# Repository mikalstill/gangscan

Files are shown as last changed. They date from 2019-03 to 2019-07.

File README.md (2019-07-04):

Introduction
============

Gang Scan is a simple attendance tracking system built for Scouts ACT's
Canberra Gang Show. It uses custom RFID badge reader devices based on
Raspberry Pis to track badge read events, which are streamed to a server.
Each badge reader is configured to either be an "in" or and "out" reader, and
therefore attendance can be calculated. The badge readers will queue scan
events and stream them to the server later if connectivity is intermittent.

Structure
=========

The structure of this repository is:

* deploy: deployment scripts.
* eagle: PCB layouts for the gang scan hardware.
* gangscan: the software stack for the badge readers.
* gangserver: the server side of the application.
* idcards: is a simple ID card art generation script with sample data. See the README in that directory for more detail.
* vendor: git sub-modules for dependancies.

Installation: Common Steps
==========================

First off, flash the latest raspberry pi debian to an SD card. You can find
it at https://www.raspberrypi.org/downloads/raspbian/ . I have been using the
Debian Stretch Lite image for development. I use Balena Etcher to flash the
SD cards, and this process is well documented elsewhere.

Insert this SD card into your raspberry pi and boot it. You'll need to have
the raspberry pi plugged into a HDMI monitor and USB keyboard and mouse for
the next steps.

* Log in: username is "pi" and password is "raspberry".
* Change the password: "passwd".
* Configure the pi:
  * `sudo raspi-config`
  * Join wifi (network options)
  * Enable ssh (interfacing options)
  * Expand filesystem (advanced options)
  * Reboot
* Update the operating system:
  * `sudo apt-get update`
  * `sudo apt-get dist-upgrade`
* Install ansible:
  * `sudo apt-get install python3-pip`
  * `sudo pip3 install ansible`
* Install git and vim, then clone gangscan:
  * `sudo apt-get install git vim`
  * `git clone https://github.com/mikalstill/gangscan`
  * `cd gangscan`
  * `git submodule update --init --recursive`

Installation: Gang Server
=========================

The gangserver advertises itself using a homegrown UDP protocol. It is assumed that
the server will be running on raspberry pi running debian (called raspbian).
This can be one of the gangscan devices if that is desirable for your
deployment. First follow the common installation steps above, once those
steps are done we have enough of a system to be able to do the rest of the
install via ansible plays.

Run ansible to install gangserver:

~~~~
$ /usr/local/bin/ansible-playbook -i hosts deploy/gangserver.yml
~~~~

This should install all the required software for the gangserver, and start
it on port 80. The server advertises itself on the network using avahi /
zeroconf networking, so you don't need to have the server running on a
machine with a known IP. However, knowing the IP of the server is very
useful for viewing reports, so perhaps put it on a static IP anyway.

Installation: Gang Scan
=======================

The RFID reader hardware runs a program called gangscan. To install it,
follow the common installation steps above, and then install gangscan with
ansible:

~~~~
$ /usr/local/bin/ansible-playbook -i hosts deploy/gangscan.yml
~~~~

Because the ansible changes the boot configuration of the raspberry pi (it
turns on SPI and PWN audio), you need to reboot before the scanner will work
correctly:

~~~~
$ sudo reboot
~~~~

Checking the status of Gang Scan
================================

Because Gang Scan uses systemd, you can check the status of the various
components using systemd commands. To see the general status of the server,
do this:

~~~~
$ sudo systemctl status gangserver
~~~~

To see recent log messages from the server, do this:

~~~~
$ sudo journalctl -u gangserver
~~~~

Hardware helpers
================

Gang Scan devices use an identity EEPROM to make sure the software is talking
to the right version of the hardware. To program EEPROMs, install the
developer software with Ansible like this:

~~~~
$ /usr/local/bin/ansible-playbook -i hosts deploy/eeprom_writer.yml
~~~~

Now we can program some EEPROMs. You'll need to build a little programming
circuit (see the notes below), and then run this tool:

~~~~
$ cd /home/pi/hats/eepromutils
$ sudo sh eepflash.sh -w -f=/home/pi/gangscan/eeprom/eeprom_settings.eep \
  -t=24c256 -d=1
~~~~

For more details about Raspberry Pi HAT EEPROMs, see my notes at
https://www.madebymikal.com/raspberry-pi-hat-identity-eeproms-a-simple-guide/

Credits
=======

Various parts of Gang Scan draw on previous Open Source or Creative Commons
artifacts:

* Material Design Icons are from https://cdn.materialdesignicons.com/3.5.95/.
** This includes the TTF Font, as well as account.png
* BebaseNeue is licensed under the creative commons and is from https://fontlibrary.org/en/font/bebas
* blip.wav is "Robot Blip" by Marianne Gagnon from http://soundbible.com/1682-Robot-Blip.html which is released under a CC Attribution 3.0 license.

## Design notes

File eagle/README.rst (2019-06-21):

Board notes:

* v0.1: the first board to be fabbed. Has LCD and RFID on different SPI buses.
* ... (incremental tweaking including better track sizing, and nicer labels)
* v0.6: the second board to be fabbed. Has LCD and RFID on different SPI buses, and prototype
  audio support. Unfortunately, SPI1 conflicts with the audio hardware and the RFID reader
  needs to be moved onto SPI0 for this to work correctly.
* v0.7: tweaked footprint labels to be more accurate. Moved RFID reader onto SPIO bus to free
  up pins for audio. Corrected MKT capacitor pitch to 5mm.
* v0.8: correct resistor pitch (RCL_0207/7); connect RFID IRQ line to Raspberry Pi for
  later use (reduce CPU load for RFID reads by avoiding polling); moved LiPo socket down a
  little so the JST connector fits more naturally into a case; added an i2c EEPROM to
  comply with the HAT specification.

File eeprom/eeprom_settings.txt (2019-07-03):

########################################################################
# EEPROM settings text file
#
# Edit this file for your particular board and run through eepmake tool,
# then use eepflash tool to write to attached HAT ID EEPROM 
#
# Tools available:
#  eepmake   Parses EEPROM text file and creates binary .eep file
#  eepdump   Dumps a binary .eep file as human readable text (for debug)
#  eepflash  Write or read .eep binary image to/from HAT EEPROM
#
########################################################################

########################################################################
# Vendor info

# 128 bit UUID. If left at zero eepmake tool will auto-generate
# RFC 4122 compliant UUID
product_uuid 00000000-0000-0000-0000-000000000000

# 16 bit product id
product_id 0x0001

# 16 bit product version
product_ver 0x0008

# ASCII vendor string  (max 255 characters)
vendor "madebymikal.com"

# ASCII product string (max 255 characters)
product "GangScan"

########################################################################
# GPIO bank settings, set to nonzero to change from the default.
# NOTE these setting can only be set per BANK, uncommenting any of
# these will force the bank to use the custom setting.

# drive strength, 0=default, 1-8=2,4,6,8,10,12,14,16mA, 9-15=reserved
gpio_drive 0

# 0=default, 1=slew rate limiting, 2=no slew limiting, 3=reserved
gpio_slew 0

# 0=default, 1=hysteresis disabled, 2=hysteresis enabled, 3=reserved
gpio_hysteresis 0

# If board back-powers Pi via 5V GPIO header pins:
# 0 = board does not back-power
# 1 = board back-powers and can supply the Pi with a minimum of 1.3A
# 2 = board back-powers and can supply the Pi with a minimum of 2A
# 3 = reserved
# If back_power=2 then USB high current mode will be automatically 
# enabled on the Pi
back_power 0

########################################################################
# GPIO pins, uncomment for GPIOs used on board
# Options for FUNCTION: INPUT, OUTPUT, ALT0-ALT5
# Options for PULL: DEFAULT, UP, DOWN, NONE
# NB GPIO0 and GPIO1 are reserved for ID EEPROM so cannot be set

#         GPIO  FUNCTION  PULL
#         ----  --------  ----
#setgpio  2     INPUT     DEFAULT
#setgpio  3     INPUT     DEFAULT
#setgpio  4     INPUT     DEFAULT
#setgpio  5     INPUT     DEFAULT
#setgpio  6     INPUT     DEFAULT
#setgpio  7     INPUT     DEFAULT
#setgpio  8     INPUT     DEFAULT
#setgpio  9     INPUT     DEFAULT
#setgpio  10    INPUT     DEFAULT
#setgpio  11    INPUT     DEFAULT
#setgpio  12    INPUT     DEFAULT
#setgpio  13    INPUT     DEFAULT
#setgpio  14    INPUT     DEFAULT
#setgpio  15    INPUT     DEFAULT
#setgpio  16    INPUT     DEFAULT
#setgpio  17    INPUT     DEFAULT
#setgpio  18    INPUT     DEFAULT
#setgpio  19    INPUT     DEFAULT
#setgpio  20    INPUT     DEFAULT
#setgpio  21    INPUT     DEFAULT
#setgpio  22    INPUT     DEFAULT
#setgpio  23    INPUT     DEFAULT
#setgpio  24    INPUT     DEFAULT
#setgpio  25    INPUT     DEFAULT
#setgpio  26    INPUT     DEFAULT
#setgpio  27    INPUT     DEFAULT

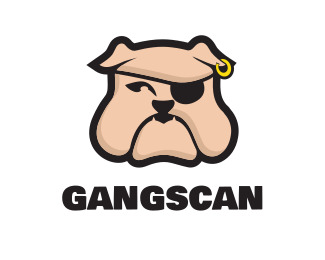
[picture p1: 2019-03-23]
idcards/logo.jpg

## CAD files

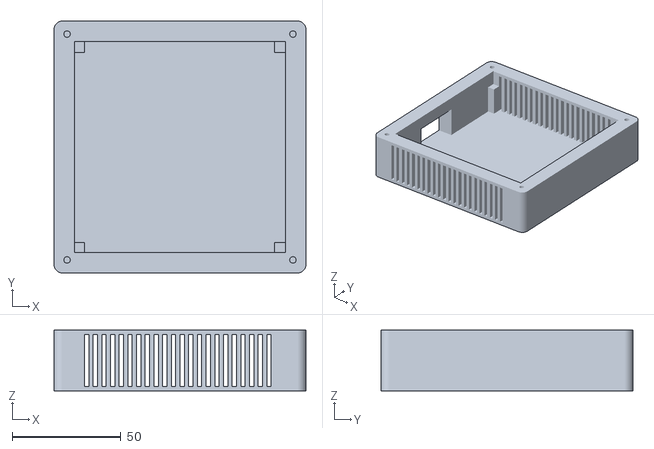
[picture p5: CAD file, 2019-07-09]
cases/gangscan_case.stl
116.0 x 116.0 x 28.0

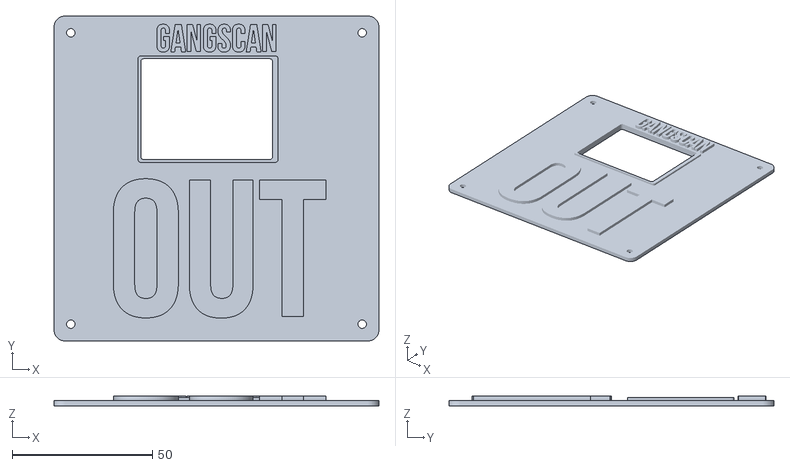
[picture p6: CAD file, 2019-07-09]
cases/gangscan_out.stl
116.0 x 116.0 x 3.50

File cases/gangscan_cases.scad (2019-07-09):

// Gangscan case
// This is a case built for the gangscan project
// https://github.com/mikalstill/gangscan
// the BebasNeue.ttf font from the gangscan directory needs to be installed to render correctly

// The dimensions of the board are added here as debug objects
// gangscan board
%cube([96,96,1.7]);
// screen board
%translate([8.25,53.75,3.1]) cube([68,40,1.5]);
// screen hole
%translate([21,54.75,4.6]) cube([48,36,5.5]); // 4mm extra to see where the hole goes. Needs to be smaller than the screen bracket
// rfid reader
%translate([8.25,8,3.7]) cube([60,40,1.5]);
// Raspberry Pi Zero W
%translate([8.25,21,-18]) cube([30,65,18]);


module PowerSymbol (thickness) {
    // we need a power symbol on the side
    linear_extrude (height = thickness, center = true, convexity = 1, twist = 0, slices = 10, scale = 1.0, $fn = 100) {
        union() {
            difference () {
                circle (10, $fn=100);
                circle (8, $fn=100);
                translate ([-3,0,0]) square ([6,10]);
            }
            translate ([-1,2,0]) square ([2,10]);
        } 
    }
}// power symbol

module USBSymbol (thickness) {
    // we don't really need a usb symbol
    // but it's a good learning exercise to have done this by hand
    linear_extrude (height = thickness, center = true, convexity = 1, twist = 0, slices = 10, scale = 1.0, $fn = 100) {
    // This array is the points to generate the USB trident without the circles    
        usbTrident=[[0,0],[0,0.5],[6,0.5],[10,5],[15,5], [15,4],[10,4],[7,0.5],[20,0.5],[20,2],[23,0],[20,-2],[20,-0.5],[10,-0.5],[13,-4],[16,-4],[16,-3],[19,-3],[19,-6],[16,-6],[16,-5],[13,-5],[9,-0.5]
    ,[0,-0.5]];
        union () {
            polygon(usbTrident);
            // add the circles to the shape
            circle (2, $fn=50); 
            translate ([15,4.5,0]) circle (1.5, $fn=50); 
        } // union
    } //linear_extrude
}// USBsymbol

module RoundBox (x, y, z, r) {
  $fn=50;
  translate ([r, r, 0]) minkowski()
  {
    cube([x-(2*r), y-(2*r), z]);
    cylinder(r=r, h=z);
  }
} // RoundBox



module Lid (direction) {
// Top Half with the out text
// uncomment the rotate/translate for export
//rotate([180,0,0]) translate ([0, -90, -10])
    difference() {
        union() {
            translate ([-10, -10, 8]) RoundBox(116, 116, 1, 4);  // box height is double the value set
            translate ([20, 53.75, 10]) RoundBox(50, 38, 0.5,1); // Add a border to the screen

            // gangscan text
            translate ([ 48,98, 10]) linear_extrude (height = 3, center = true, convexity = 1, twist = 0, slices = 10, scale = 1.0, $fn = 100) {
    text("GANGSCAN", halign="center", valign="center", font="Bebas Neue:style=Regular");
            }
            // direction text
            translate ([48, 22.5, 10]) linear_extrude (height = 3, center = true, convexity = 1, twist = 0, slices = 10, scale = 1.0, $fn = 100) {
    text(direction, halign="center", valign="center", font="Bebas Neue:style=Regular", size=50);
            }
        }
        // screen hole
        translate([21,54.75,0]) RoundBox(47, 36, 10.5,1);
        // Holes for the screws
        translate ([-4, -4, 3]) cylinder(8, d=3, $fn=50);
        translate ([-4, 100, 3]) cylinder(8, d=3, $fn=50);
        translate ([100, -4, 3]) cylinder(8, d=3, $fn=50);
        translate ([100, 100, 3]) cylinder(8, d=3, $fn=50);
    } // difference
} // lid ()




module Case() {
// Bottom Half
// uncomment the translate to export
    union() {
        difference() {
            translate ([-10, -10, -20]) RoundBox(116, 116, 14, 4);  // box height is double the value set
            // cut out the hole for the board
            translate([-0.5, -0.5, -18]) cube([97,97,28]);
            // and the holes for the screws
            translate ([-4, -4, -15]) cylinder(25, d=3, $fn=50);
            translate ([-4, 100, -15]) cylinder(25, d=3, $fn=50);
            translate ([100, -4, -15]) cylinder(25, d=3, $fn=50);
            translate ([100, 100, -15]) cylinder(25, d=3, $fn=50);
            // USB hole for the raspberry pi
            translate([-10, 25, -18]) cube([20,30,18]);
            // show which side is power
            translate([-10, 15, -10]) rotate ([90,0,-90]) scale ([0.5, 0.5, 1]) PowerSymbol (3);
            // and USB
            translate([-10, 65, -14]) rotate ([90,-90,-90]) scale ([0.5, 0.5, 1]) USBSymbol (3);
            // add some vents
            for (counter = [1:22]) {
                translate([0+(4 * counter), -10, -18]) cube([2,20,24]);
                translate([0+(4 * counter), 86, -18]) cube([2,20,24]);
            }
        } // difference
        // supports for the board
        translate ([-1, -1, -18]) cube([5,5,17]);
        translate ([-1, 91.5, -18]) cube([5,5,17]);
        translate ([91.5, -1, -18]) cube([5,5,17]);
        translate ([91.5, 91.5, -18]) cube([5,5,17]);
    } // union
} // case

// align them nicely
translate ([0, 0, -8]) Lid ("IN");
translate ([0, -120, -8]) Lid ("OUT");
translate ([0, 120, 20]) Case () ;

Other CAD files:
cases/gangscan_in.stl

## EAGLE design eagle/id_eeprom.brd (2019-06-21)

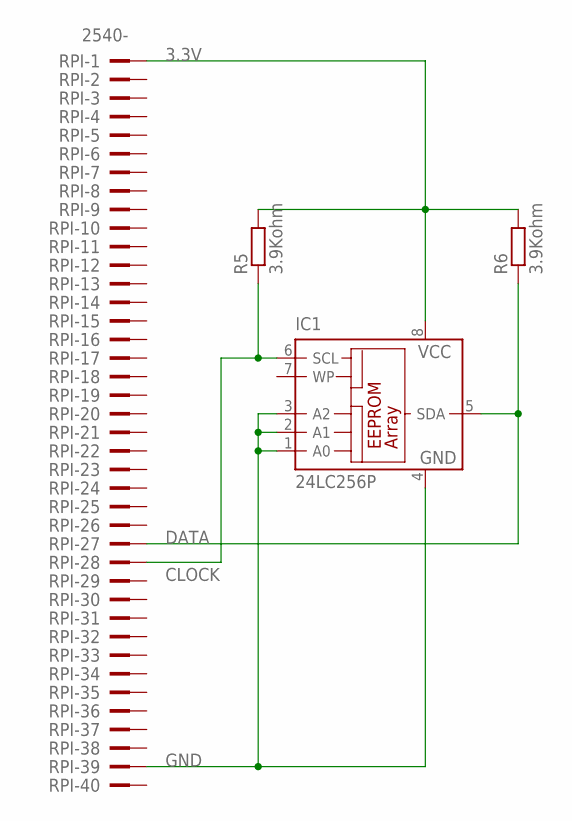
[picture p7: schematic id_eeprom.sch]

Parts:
IC1: 24LC256P; DIL8
R5, R6: 3.9Kohm; 0207/7
RPI: 2540-; PAK100/2500-40

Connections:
3.3V: IC1.8 (VCC), R5.2, R6.2, RPI.1
CLOCK: IC1.6 (SCL), R5.1, RPI.28
DATA: IC1.5 (SDA), R6.1, RPI.27
GND: IC1.1 (A0), IC1.2 (A1), IC1.3 (A2), IC1.4 (GND), RPI.39

Board: 2 copper layers, 4 parts (0 on the bottom side), 4 nets, no tracks yet.

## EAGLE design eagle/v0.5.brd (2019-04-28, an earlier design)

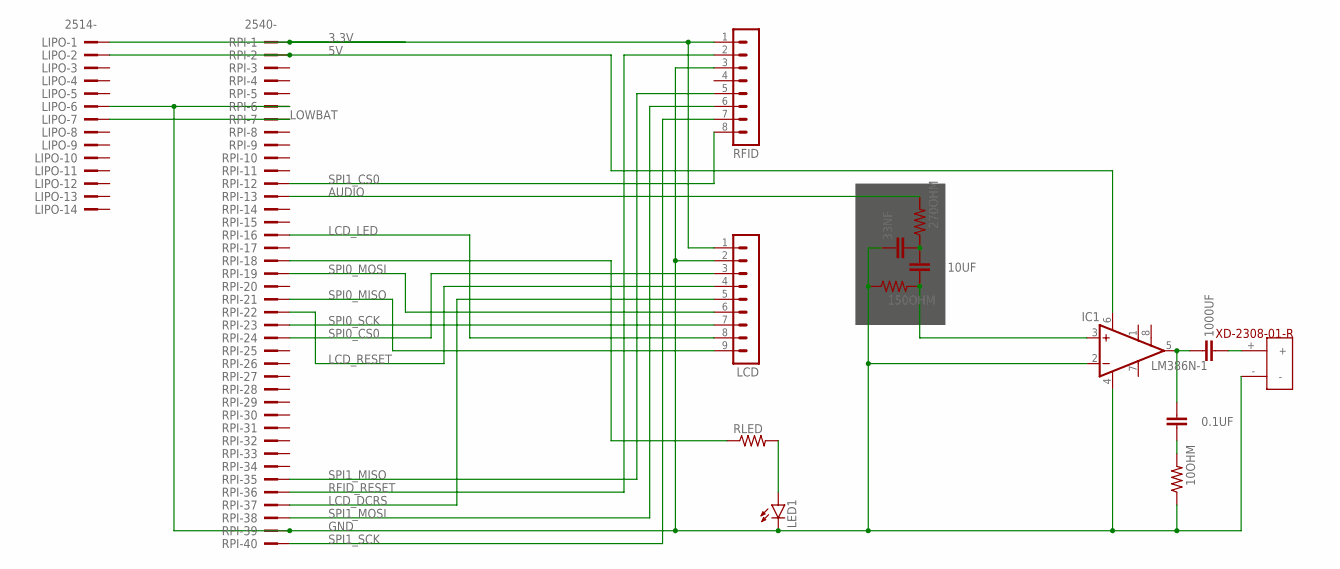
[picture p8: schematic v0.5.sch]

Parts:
0.1UF, 10UF, 33NF, 1000UF: C-EU025-025X050; C025-025X050
10OHM, 150OHM, 270OHM: R-US_0204/5; 0204/5
IC1: LM386N-1; DIL08
LCD: MA09-1
LED1: LED3MM
LIPO: 2514-; PAK100/2500-14
RFID: MA08-1
RLED: R-US_0204/5; 0204/5
RPI: 2540-; PAK100/2500-40
U$1: XD-2308-01-R

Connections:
3.3V: LCD.1, LIPO.1, RFID.1, RPI.1
5V: IC1.6 (VS), LIPO.2, RPI.2
AUDIO: 270OHM.2, RPI.13
GND: 10OHM.1, 33NF.1, 150OHM.1, IC1.2 (-IN), IC1.4 (GND), LCD.2, LED1.K (C), LIPO.6, RFID.3, RPI.6, RPI.39, U$1.-
LCD_DCRS: LCD.5, RPI.37
LCD_LED: LCD.8, RPI.16
LCD_RESET: LCD.4, RPI.22
LOWBAT: LIPO.7, RPI.7
unnamed: 10UF.2, 33NF.2, 270OHM.1
unnamed: 10UF.1, 150OHM.2, IC1.3 (+IN)
unnamed: RLED.1, RPI.18
unnamed: 0.1UF.2, 1000UF.2, IC1.5 (OUT)
unnamed: 1000UF.1, U$1.+
unnamed: 0.1UF.1, 10OHM.2
unnamed: LED1.A, RLED.2
RFID_RESET: RFID.2, RPI.36
SPI0_CS0: LCD.3, RPI.24
SPI0_MISO: LCD.9, RPI.21
SPI0_MOSI: LCD.6, RPI.19
SPI0_SCK: LCD.7, RPI.23
SPI1_CS0: RFID.8, RPI.12
SPI1_MISO: RFID.5, RPI.35
SPI1_MOSI: RFID.6, RPI.38
SPI1_SCK: RFID.7, RPI.40

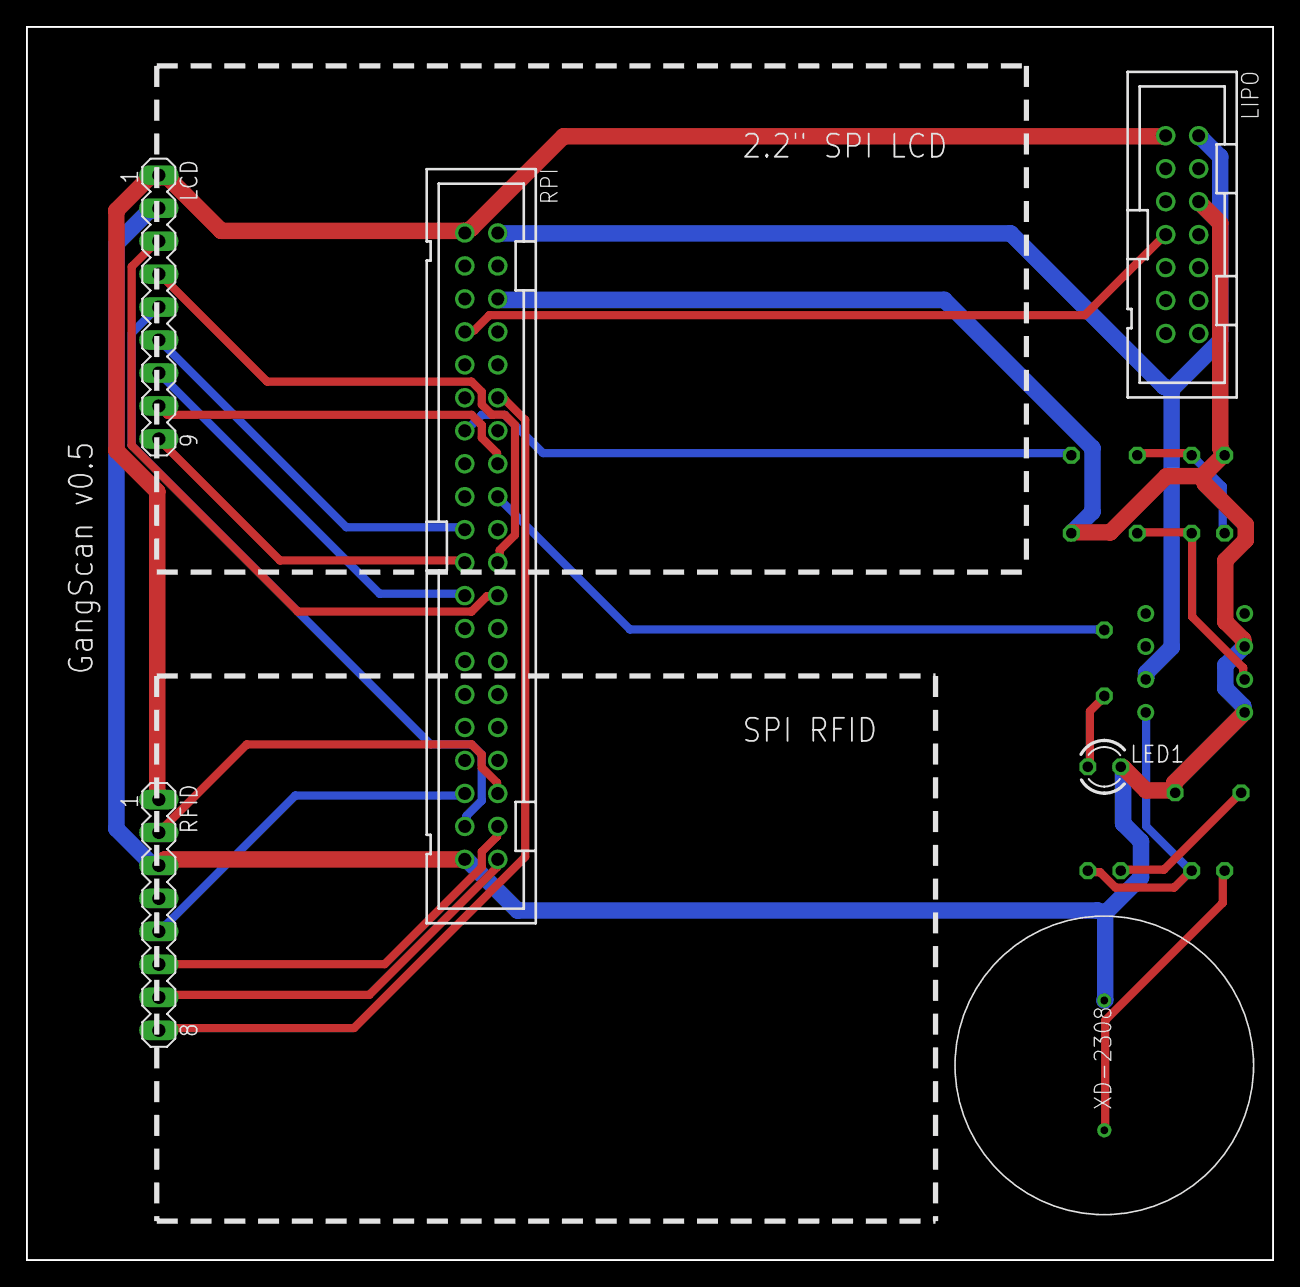
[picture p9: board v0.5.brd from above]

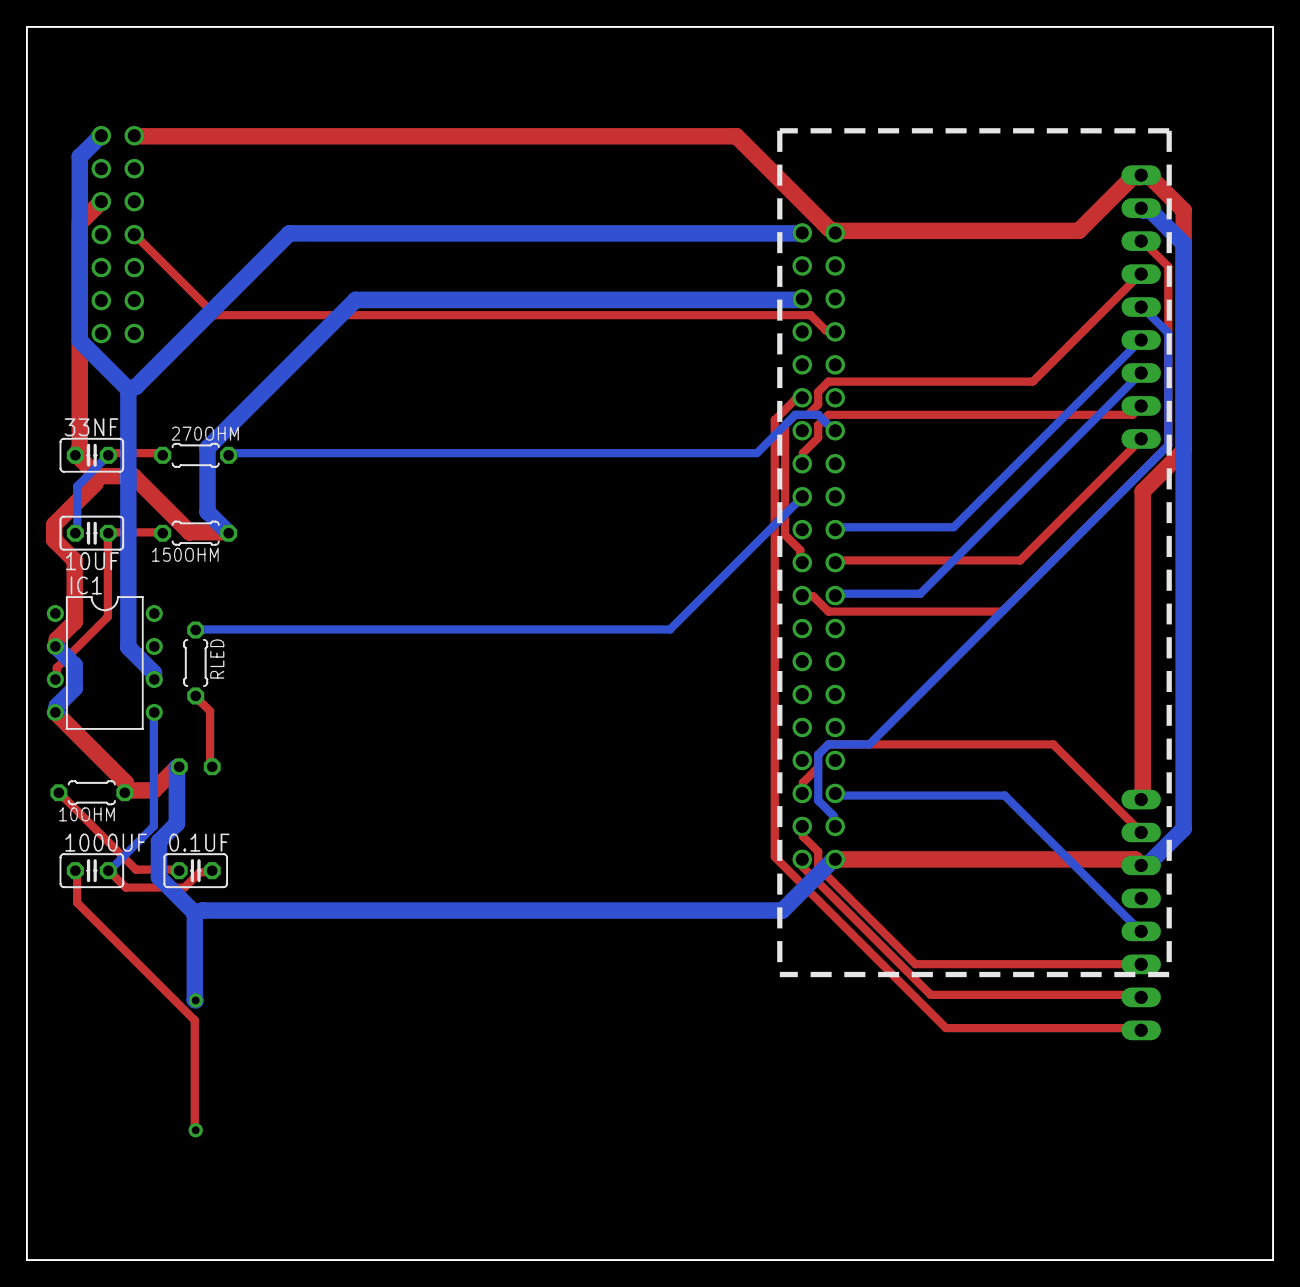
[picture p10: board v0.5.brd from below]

Board: 2 copper layers, 96.0 x 95.0 mm, 15 parts (9 on the bottom side), 24 nets.

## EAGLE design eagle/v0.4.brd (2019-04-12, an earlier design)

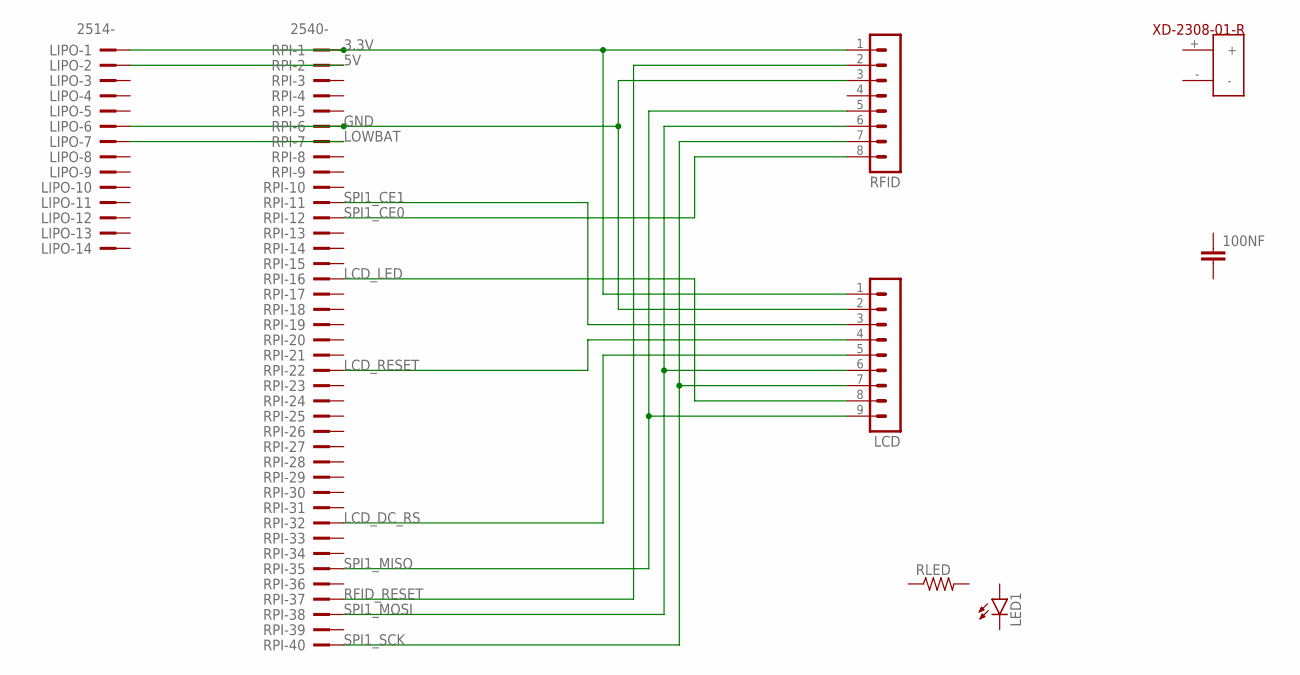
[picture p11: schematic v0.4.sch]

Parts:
100NF: C-EU025-025X050; C025-025X050
LCD: MA09-1
LED1: LED3MM
LIPO: 2514-; PAK100/2500-14
RFID: MA08-1
RLED: R-US_0204/5; 0204/5
RPI: 2540-; PAK100/2500-40
U$1: XD-2308-01-R

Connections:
3.3V: LCD.1, LIPO.1, RFID.1, RPI.1
5V: LIPO.2, RPI.2
GND: LCD.2, LIPO.6, RFID.3, RPI.6
LCD_DC_RS: LCD.5, RPI.32
LCD_LED: LCD.8, RPI.16
LCD_RESET: LCD.4, RPI.22
LOWBAT: LIPO.7, RPI.7
RFID_RESET: RFID.2, RPI.37
SPI1_CE0: RFID.8, RPI.12
SPI1_CE1: LCD.3, RPI.11
SPI1_MISO: LCD.9, RFID.5, RPI.35
SPI1_MOSI: LCD.6, RFID.6, RPI.38
SPI1_SCK: LCD.7, RFID.7, RPI.40

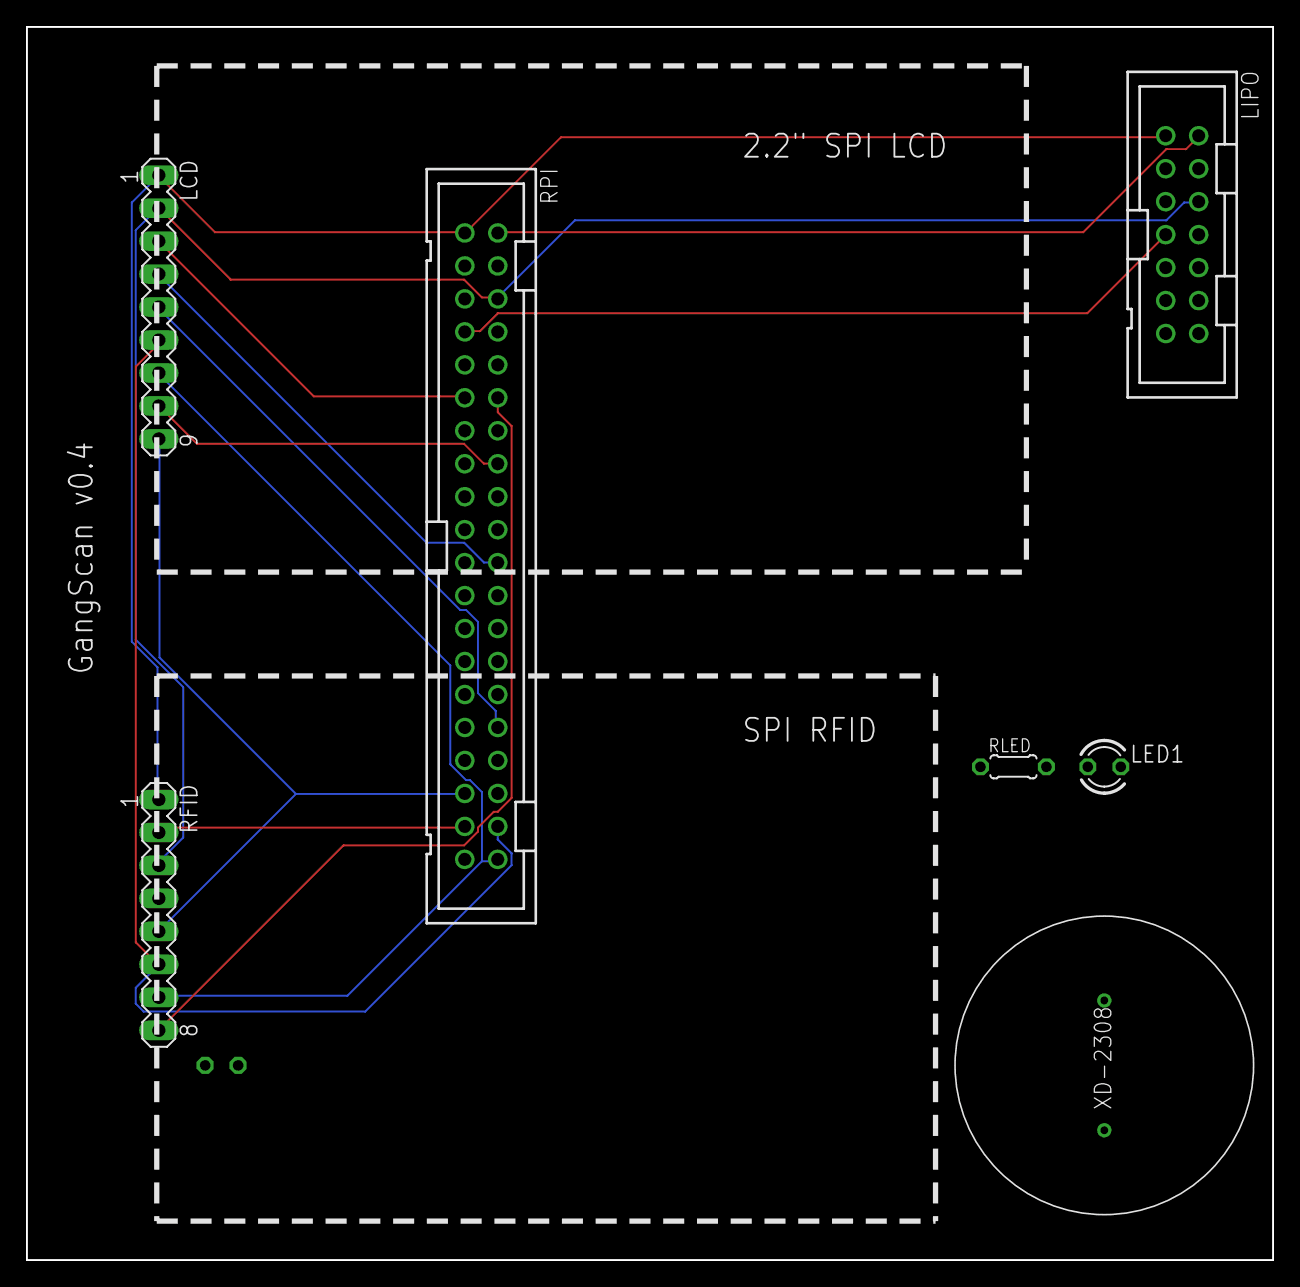
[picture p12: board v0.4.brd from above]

Board: 2 copper layers, 96.0 x 95.0 mm, 8 parts (1 on the bottom side), 13 nets.

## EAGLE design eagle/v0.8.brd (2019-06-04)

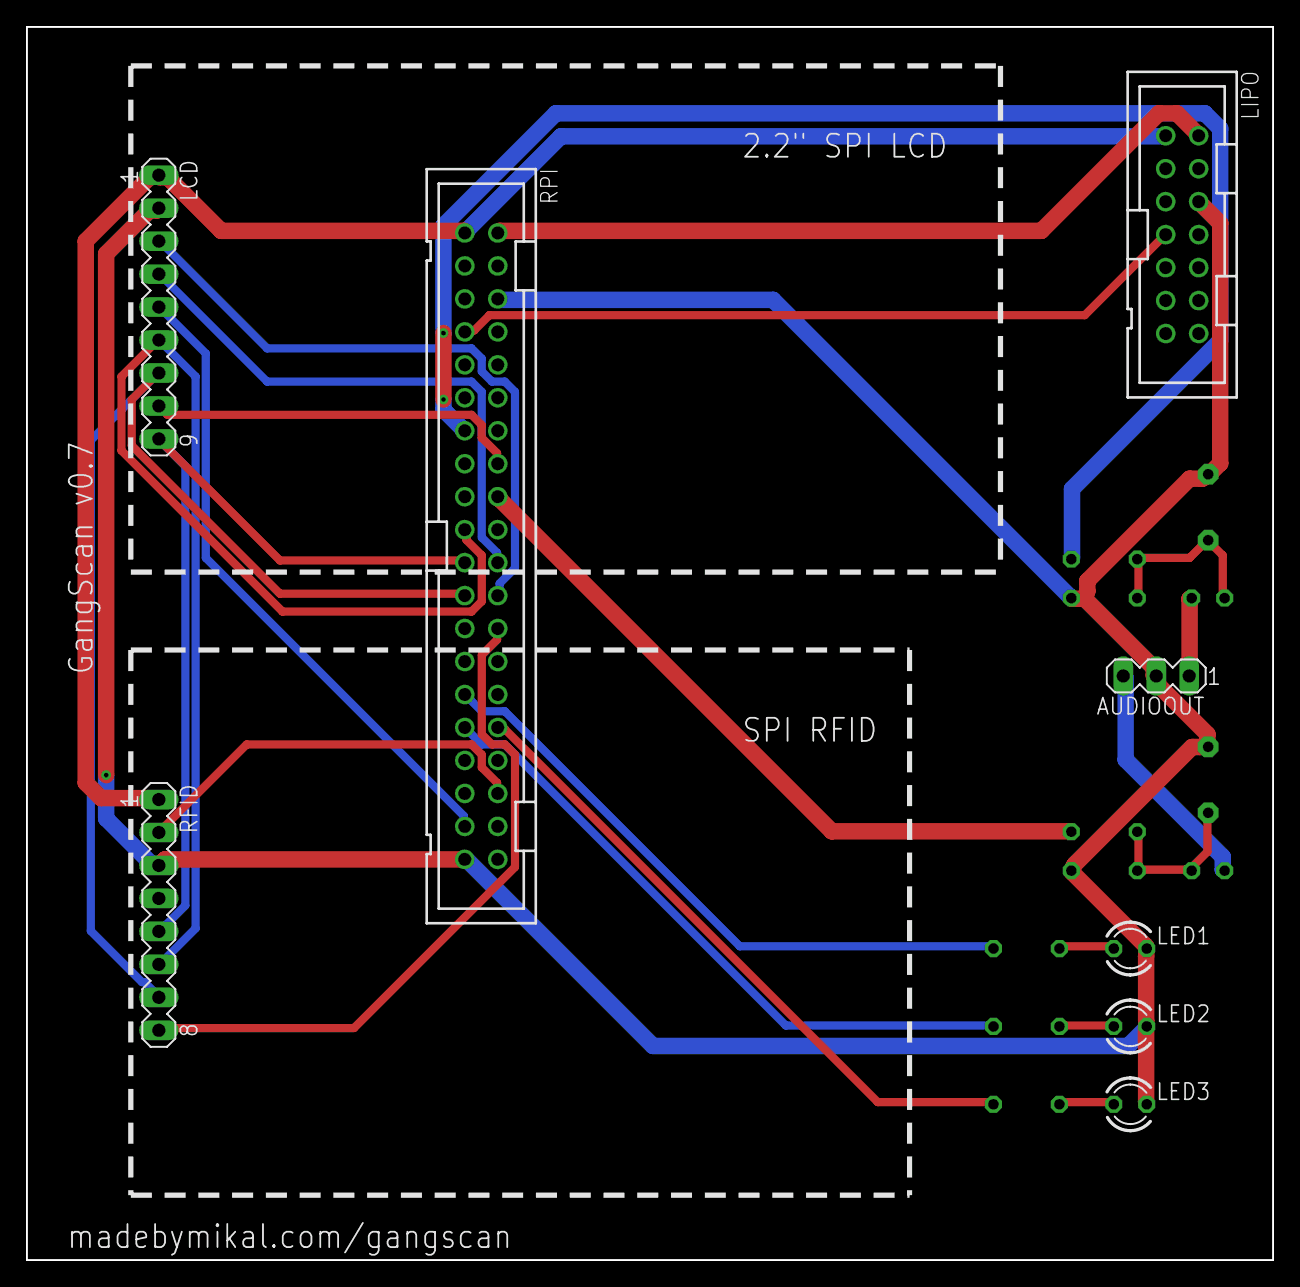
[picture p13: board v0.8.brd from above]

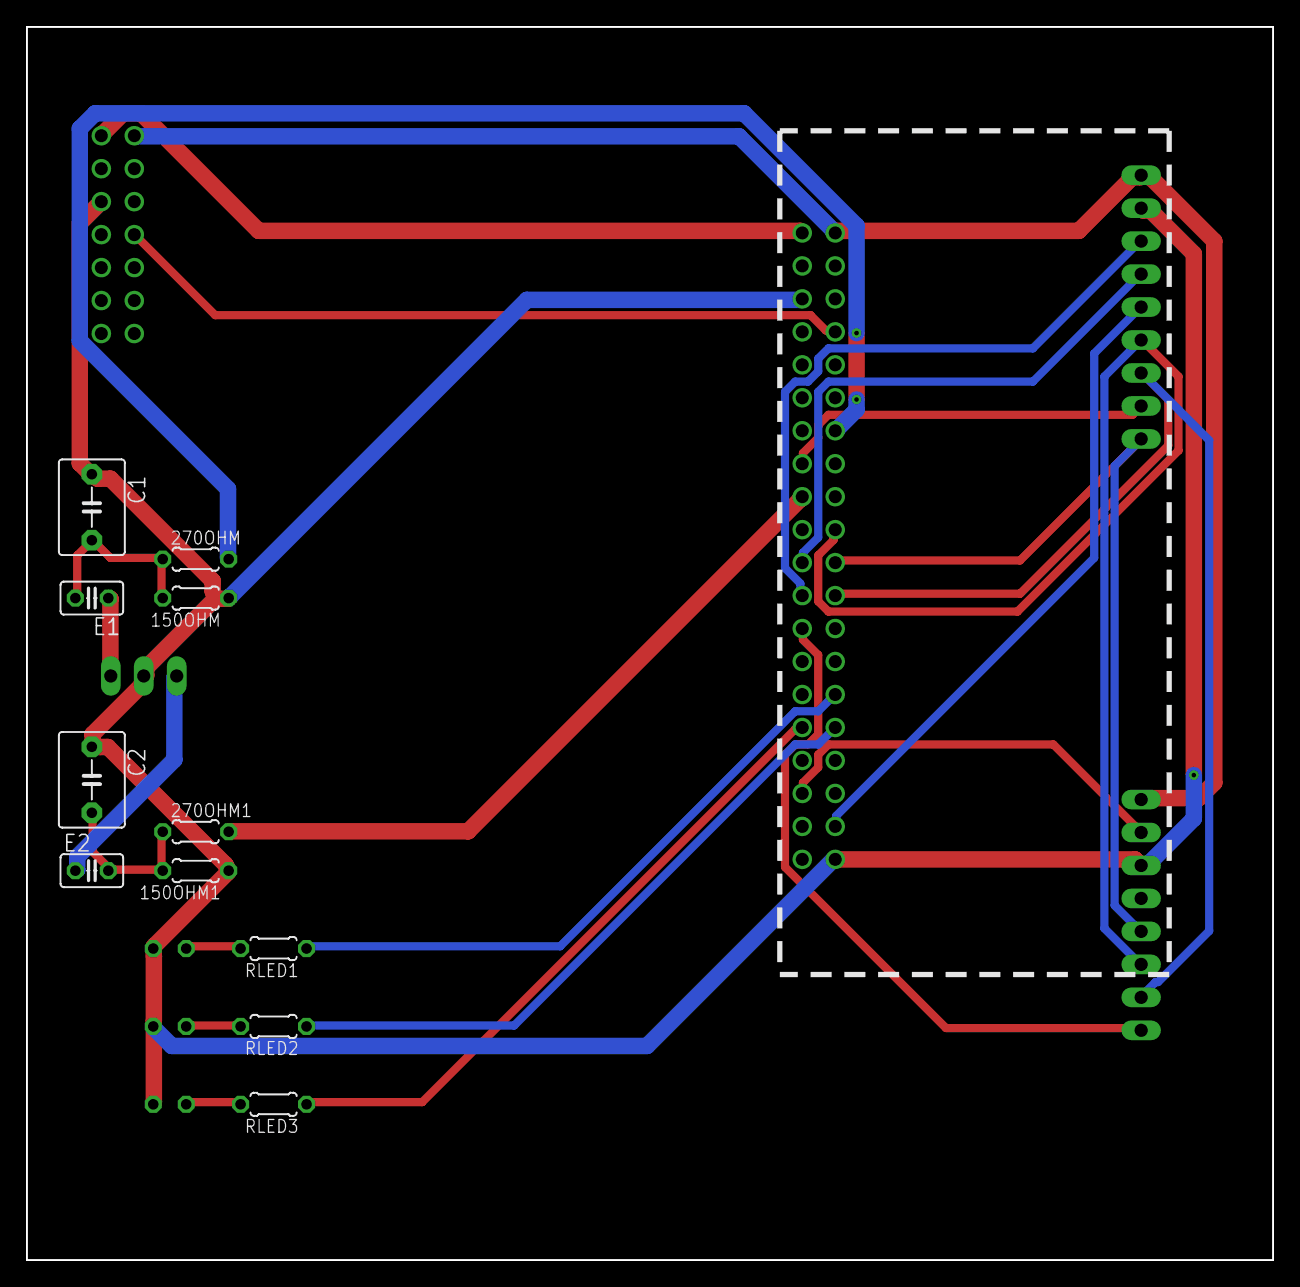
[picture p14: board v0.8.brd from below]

Board: 2 copper layers, 96.0 x 95.0 mm, 19 parts (11 on the bottom side), 25 nets.

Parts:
150OHM, 150OHM1, 270OHM, 270OHM1: 0204/5
AUDIOOUT: MA03-1
C1, C2: 33nF; C5B5
E1, E2: 1uF; C025-025X050
LCD: MA09-1
LED1, LED2, LED3: LED3MM
LIPO: 2514-; PAK100/2500-14
RFID: MA08-1
RLED1, RLED2, RLED3: 0204/5
RPI: 2540-; PAK100/2500-40

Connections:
3.3V: LCD.1, LIPO.1, RFID.1, RPI.1
5V: LIPO.2, RPI.2
AUDIO1: 270OHM.2, RPI.13
AUDIO2: 270OHM1.2, RPI.18
GND: 150OHM.1, 150OHM1.1, AUDIOOUT.2, C1.1, C2.1, LCD.2, LED1.K, LED2.K, LED3.K, LIPO.6, RFID.3, RPI.6, RPI.39
LCD_DCRS: LCD.5, RPI.37
LCD_LED: LCD.8, RPI.16
LCD_RESET: LCD.4, RPI.22
LOWBAT: LIPO.7, RPI.7
unnamed: 150OHM.2, 270OHM.1, C1.2, E1.2
unnamed: LED2.A, RLED2.2
unnamed: LED3.A, RLED3.2
unnamed: RLED1.1, RPI.29
unnamed: RLED2.1, RPI.31
unnamed: RLED3.1, RPI.32
unnamed: 150OHM1.2, 270OHM1.1, C2.2, E2.2
unnamed: AUDIOOUT.1, E1.1
unnamed: AUDIOOUT.3, E2.1
unnamed: LED1.A, RLED1.2
RFID_RESET: RFID.2, RPI.36
SPI0_CS0: LCD.3, RPI.24
SPI0_CS1: RFID.8, RPI.26
SPI0_MISO: LCD.9, RFID.5, RPI.21
SPI0_MOSI: LCD.6, RFID.6, RPI.19
SPI0_SCK: LCD.7, RFID.7, RPI.23

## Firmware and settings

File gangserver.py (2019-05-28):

#!/usr/bin/python

import datetime
import json
import mimetypes
import os
import time

from flask import Flask
from flask import Response
from flask import request
from flask import send_file
from flask_restful import Api
from flask_restful import Resource

from jinja2 import Template

import filequeue


app = Flask(__name__)
api = Api(app)


# Read config and data
with open('config.json') as f:
    config = json.loads(f.read())

queue = filequeue.FileQueue('gangscan-%s' % config['device-name'])
mimetypes.init()


class Root(Resource):
    def get(self):
        # Read template and data
        with open('report.html.tmpl') as f:
            t = Template(f.read())
        with open('groupings.json') as f:
            groupings = json.loads(f.read())
        with open('status.json') as f:
            status = json.loads(f.read())

        # Rearrange the data
        person_to_group = {}
        for group in groupings:
            for person in groupings[group]:
                person_to_group[person] = group
        
        by_group = {}
        for person in status:
            by_group.setdefault(person_to_group[person], {})
            by_group[person_to_group[person]].setdefault('in', [])
            by_group[person_to_group[person]].setdefault('out', [])
            by_group[person_to_group[person]][status[person]].append(person)

        in_groups = []
        out_groups = []
        for group in by_group:
            in_groups.append({
                'name': group,
                'members': by_group[group]['in']
            })
            out_groups.append({
                'name': group,
                'members': by_group[group]['out']
            })
        
        # Do a dance to return HTML not JSON
        resp = Response(
            t.render(
                timestamp=str(datetime.datetime.now()),
                in_groups=in_groups,
                out_groups=out_groups
            ),
            mimetype='text/html')
        resp.status_code = 200
        return resp


class Local(Resource):
    def get(self, path):
        filepath = os.path.join('gangserver', path.replace('..', ''))
        if not os.path.exists(filepath):
            resp.status_code = 404
            return resp

        mime = mimetypes.MimeTypes().guess_type(path)[0]
        return send_file(
            filepath,
            mimetype=mime,
            attachment_filename=path)


class Health(Resource):
    def get(self, device):
        print('%s Health check from %s' %(datetime.datetime.now(), device))
        return 'OK'


class Event(Resource):
    def __init__(self):
        self.queue = filequeue.FileQueue('gangserver-%s'
                                         % config['device-name'])

    def put(self, event_id):
        data = json.loads(request.form['data'])
        data['timestamp-server'] = time.time()

        # Events look like this:
        # {
        #     "cardid": 744452027206, 
        #     "device": "gangscan1", 
        #     "event_id": "5362ef36-3f43-41d5-b7ac-e47b400a664f", 
        #     "location": "out", 
        #     "outcome": true, 
        #     "owner": "Ben Ellis", 
        #     "sha": "35ef6d", 
        #     "signature": "55e1ffa7b1...cb54463f98f46b578", 
        #     "timestamp-device": 1553634527.921784, 
        #     "timestamp-server": 1553634528.421658, 
        #     "timestamp-transferred": 1553634527.924872
        # }
        with open('status.json') as f:
            status = json.loads(f.read())
        status[data['owner']] = data['location']
        with open('status.json', 'w') as f:
            f.write(json.dumps(status, indent=4, sort_keys=True))

        print('%s Stored event %s: %s'
              %(datetime.datetime.now(), event_id, data))
        self.queue.store_event('received', event_id, data)
        return {event_id: data}


api.add_resource(Root, '/')
api.add_resource(Local, '/local/<string:path>')
api.add_resource(Health, '/health/<string:device>')
api.add_resource(Event, '/event/<string:event_id>')

if __name__ == '__main__':
    app.run(host='0.0.0.0', debug=True)

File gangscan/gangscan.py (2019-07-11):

#!/usr/bin/python

# This code is derived from the work of BehindTheSciences.com and Brian Lavery

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
import datetime
import fcntl
import hashlib
import json
import os
import psutil
import requests
import select
import socket
import spidev
import subprocess
import sys
import time
import traceback
import uuid

import RPi.GPIO as GPIO

from PIL import Image
from PIL import ImageDraw
from PIL import ImageFont

import configcache
import filequeue
from lib_tft24T import TFT24T
import util


# For LCD TFT GPIOs. Numbering is GPIO.
DC = 26
RST = 25
LED = 23

# Constants
ICON_SIZE = 30


def new_icon(icon, font, inset):
    img = Image.new('RGBA', (320, 240))
    img_writer = ImageDraw.Draw(img)
    width, height = img_writer.textsize(icon, font=font)
    img_writer.text(((ICON_SIZE - width) / 2 + 5, inset + 5),
                    icon, fill='black', font=font)
    util.log('Loaded %s icon' % icon_name)
    return img


util.log('Started')

# Make sure we're using supported hardware
product, version = util.hardware_ident()
util.log('Hardware product is: "%s"' % product)
util.log('Hardware version is: "%s"' % version)
if product != 'GangScan':
    util.log('Hardware product unsupported, aborting.')
    sys.exit(1)
if version != '0x0008':
    util.log('Hardware version unsupported, aborting.')
    sys.exit(1)

# Setup GPIO
GPIO.setmode(GPIO.BCM)
GPIO.setwarnings(False)

# Initialize display.
TFT = TFT24T(spidev.SpiDev(), GPIO, landscape=False)
TFT.initLCD(DC, RST, LED)
TFT.clear((125, 255, 125))
util.log('Initialized screen')

# Update clock
try:
    subprocess.check_output('sudo ntpdate -s time.nist.gov', shell=True)
    util.log('Updated the clock')
except:
    # This will fail if we don't have network connectivity
    pass

# Find old RFID reader processes and terminate them at lot
for proc in psutil.process_iter():
    try:
        pinfo = proc.as_dict(attrs=['pid', 'cmdline', 'username'])
    except psutil.NoSuchProcess:
        # Process ended before we got to kill it!
        pass
    else:
        if pinfo['cmdline'] == ['/usr/bin/python3', 'read_rfid.py']:
            util.log('Found stale process: %s' % pinfo)
            os.kill(pinfo['pid'], 9)

# Start listening for gangserver announcements
announce = socket.socket(socket.AF_INET, socket.SOCK_DGRAM)
announce.bind(('', 5000))

# Configuration
cm = configcache.ConfigManager()

# Create the file queue
queue = filequeue.FileQueue(
    os.path.expanduser('~/gangscan-%s' % cm.get('device-name', 'unknown')))

# Objects we need to draw things
icons = ImageFont.truetype('gangscan/materialdesignicons-webfont.ttf',
                           ICON_SIZE)
text = ImageFont.truetype('gangscan/BebasNeue.ttf', ICON_SIZE)
small_text = ImageFont.truetype('gangscan/BebasNeue.ttf', int(ICON_SIZE / 2))
medium_text = ImageFont.truetype('gangscan/BebasNeue.ttf', int(ICON_SIZE * 1))
giant_text = ImageFont.truetype('gangscan/BebasNeue.ttf', int(ICON_SIZE * 1.3))

images = {}
images['logo'] = Image.open('gangscan/gangscan.jpeg').convert('RGBA')
images['logo'] = images['logo'].resize((320, 240))
util.log('Loaded logo')

for (icon_name, icon, font, inset) in [
        ('wifi_on', chr(0xf5a9), icons, 0),
        ('wifi_off', chr(0xf5aa), icons, 0),
        ('connect_on', chr(0xf1f5), icons, ICON_SIZE + 5),
        ('connect_off', chr(0xf1f8), icons, ICON_SIZE),
        ('location', cm.get('location', '???'), text, (ICON_SIZE + 5) * 2)]:
    images[icon_name] = new_icon(icon, font, inset)
    
# Start the RFID reader process
(pipe_read, pipe_write) = os.pipe()
reader = subprocess.Popen(('/usr/bin/python3 gangscan/read_rfid.py '
                           '--presharedkey=%s --linger=1'
                           % cm.get('pre-shared-key', '')),
                          shell=True, stdout=pipe_write, stderr=pipe_write)

# Make the reader non-blocking
flag = fcntl.fcntl(pipe_read, fcntl.F_GETFL)
fcntl.fcntl(pipe_read, fcntl.F_SETFL, flag | os.O_NONBLOCK)

last_scanned = None
last_scanned_time = 0
last_status_time = 0

connected = False
last_netcheck_time = 0

def draw_status():
    global last_status_time

    status = images['logo']

    # Paint status icons
    if cm.get('ipaddress') != '...':
        status = Image.alpha_composite(status, images['wifi_on'])
    else:
        status = Image.alpha_composite(status, images['wifi_off'])

    if connected:
        status = Image.alpha_composite(status, images['connect_on'])
    else:
        status = Image.alpha_composite(status, images['connect_off'])

    status = Image.alpha_composite(status, images['location'])

    now = datetime.datetime.now()
    status_writer = ImageDraw.Draw(status)

    # Display time
    status_writer.text((5, 240 - (ICON_SIZE / 2) - 5),
                       '%02d:%02d' % (now.hour, now.minute),
                       fill='black',
                       font=small_text)

    # Display queue size
    queued_string = '%d queued' % queue.count_events('new')
    width, height = status_writer.textsize(
        queued_string,
        font=small_text)
    status_writer.text((320 - width - 5, 240 - (ICON_SIZE / 2) - 5),
                       queued_string,
                       fill='black',
                       font=small_text)

    # Display network address
    width, height = status_writer.textsize(cm.get('ipaddress'), font=small_text)
    status_writer.text(((320 - width) / 2, 240 - (ICON_SIZE / 2) - 5),
                       cm.get('ipaddress'),
                       fill='black',
                       font=small_text)

    # Display recently scanned person
    if time.time() - last_scanned_time < cm.get('name-linger', 5):
        font = giant_text
        if len(last_scanned) > 20:
            font = medium_text

        width, height = status_writer.textsize(
            last_scanned, font=font)
        status_writer.rectangle(
            (160 - width / 2 - 5, 120 - height / 2 - 5,
             160 + width / 2 + 5, 120 + height / 2 + 5),
            fill='white')

        fill='green'
        if last_scanned == '???':
            fill='red'

        status_writer.text(
            ((320 - width) / 2, (240 - height) / 2),
            last_scanned,
            fill=fill,
            font=font)

    last_status_time = time.time()
    TFT.display(status.rotate(90, resample=0, expand=1))
    util.uptime()
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

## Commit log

2019-03-23 Fighting RFID on the second SPI bus.
2019-04-03 Eagle design for 0.1 PCB
    [v0.1.brd, v0.1.sch]
2019-04-05 Starting to think about the next version of the PCB.
    [v0.2.brd, v0.2.sch]
2019-04-09 More work on the PCB.
    [v0.2.brd, v0.2.sch]
2019-04-09 v0.3 board
    [v0.3.brd, v0.3.sch]
2019-04-09 Library for the PCB speaker
2019-04-11 Correct lipo connections.
    [v0.3.brd, v0.3.sch]
2019-04-12 First attempt at moving everything to SPI1 so we can do PWM audio.
    [v0.4.brd, v0.4.sch]
2019-04-12 We don't need to rearrange the SPI buses.
    I was wrong, partially because I didn't realize that my labelling
    of SPI pins was ambigious. The signal that was sitting on a PWM pin
    _isn't_ part of the SPI bus, its just a GPIO signal that I can
    move to another pin. This frees up the pins I need for PWM audio
    without requiring a wholesale rearrangement of the PCB design.
    So let's do that instead. I've called it board version 0.5...
    [v0.5.brd, v0.5.sch]
2019-04-15 Change pin for LCD to make space for PWM audio and add missing file.
    [filequeue.py, gangscan.py]
2019-04-28 Add raspi boot configuration file.
    [config.txt]
2019-05-10 Let's do another run of boards, this time with more LEDs and sound half done.
    [v0.6.brd, v0.6.sch]
2019-05-20 Working on the v0.7 board.
    [v0.7.brd, v0.7.sch]
2019-05-20 Move RFID to SPI0 to free up pins for audio (board v0.7).
    [config.txt]
2019-05-21 Board version v0.7
    [v0.7.brd, v0.7.sch]
2019-05-29 Installation for gangscan and py3 fixups.
    [gangscan.py, gangserver.py, lib_tft24T.py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]
2019-05-29 config.txt stuff is now handled by ansible
    [config.txt]
2019-05-30 Fixups from testing on a production v0.7 board.
    [gangscan.py, read_rfid.py]
2019-05-31 Fix typo in config file path.
    [gangscan.py, util.py]
2019-06-04 Start thinking about a v0.8 board.
    [v0.8.brd, v0.8.sch]
2019-06-06 Add simple ID card generation script with sample data.
    [db.csv]
2019-06-06 Changes to support gang show 2018.
    [db.csv]
2019-06-10 Updated report to handle more than two locations, fixed card hashing.
    [gangserver.py, read_rfid.py, write_rfid.py]
2019-06-21 Changes to make the UI snappier.
    [gangscan.py, read_rfid.py, util.py]
2019-06-21 v0.8 board
    [id_eeprom.brd, id_eeprom.sch]
2019-06-22 Fix double encoding bug.
    [gangscan.py, read_rfid.py]
2019-06-22 Ignore stray error codes from the RFID library.
    [gangscan.py]
2019-06-22 Indicate to users card read errors.
    [gangscan.py]
2019-07-07 Filter event log by user.
2019-07-08 Create a framework for user login.
2019-07-08 Create framework for manual events.
2019-07-09 added openscad and stl files for 3d printed cases
    [gangscan_case.stl, gangscan_cases.scad, gangscan_in.stl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]
2019-07-11 Move to unbuffered IO to resolve old card reprocessing issues.
    [gangscan.py]
2020-03-08 Fix patrol name bug.
    [gangserver.py]
